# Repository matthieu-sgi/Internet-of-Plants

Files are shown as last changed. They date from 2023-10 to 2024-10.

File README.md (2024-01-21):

# Internet of Plants

The **Internet of Plants** is an innovative project that revolutionizes the way we interact with and monitor plants. By transforming plants into living sensors, we create a bridge between nature and technology. In this project, we utilize the interaction (touch) you have with the plant and its humidity level to generate real-time sonification of the data. This not only enriches our connection with nature but also provides valuable insights into plant health and well-being.

## Table of Contents

- [Introduction](#introduction)
- [Project Overview](#project-overview)
- [Hardware](#hardware)
- [Software](#software)
- [Internet and networking](#internet-and-networking)
- [Roadmap](#roadmap)

## Introduction

The Internet of Plants is a creative exploration into the realm of biotechnology and sensory augmentation. It enables us to perceive and interpret data from the natural world in a novel and engaging way. With this project, we hope to inspire a deeper appreciation for the environment and promote sustainable practices through data-driven insights. This by conducting a musical art experience.

## Project Overview

### How it Works

The core concept of the Internet of Plants is to use plants as living sensors. We collect data from the plants through two main channels:

1. **Interaction (Touch):** When you interact with a plant by touching its leaves or stems, the project senses this interaction and translates it into a unique sound.

2. **Humidity Level:** We monitor the humidity level of the soil. Changes in humidity are reflected through a different set of sounds, providing valuable feedback on the plant's environmental conditions.

### Repository Structure

    Internet of Plants/
    |-- README.md
    |-- software/
    |   |-- [Software files and source code]
    |-- hardware/
    |   |-- [Hardware design files]
    |-- media/
    |   |-- [Image files related to the project]
    |-- documentation/
    |   |-- poster/
    |   |   |-- [Poster files]
    |   |-- BOM/ # Bill of Materials
    |   |   └── pcb_bom_iop_budget.csv # BOM for the PCB and the budget
    |   |-- user_study/
    |   └──   |-- [User study files]
    └── acknowledgements.md

## Hardware

The hardware for the Internet of Plants is based on a custom-designed Printed Circuit Board (PCB). You can find detailed information about the PCB design, components, and assembly in the **PCB** folder of this repository.

## Software

The software component of this project is responsible for collecting data from the plant sensors and converting it into sonified feedback. It involves signal processing, data visualization, and sound synthesis. Detailed instructions on setting up and running the software can be found in the **Software** section of this repository.

## Internet and networking

The PCBs are made out of an ESP32, a MCU that has Wifi capabilities. The ESP32 is connected to a server that runs a Pure Data. The Pure Data patch is responsible for the sonification of the data.
This allows to connect several and many plants to the same server and to have a centralized sonification of the data.
This is done in order to do a musical art experience and to go to Ars Electronica with the project.

## Deployment

Refer to [deployment.md](https://github.com/matthieu-sgi/Internet-of-Plants/blob/main/deployment.md).

## Roadmap

- [x] Test the electronic filter for the touch interaction
- [x] Test the sound amplification circuit
- [x] Build a prototyping PCB
- [x] Build a software embedded synthesizer
- [x] Do sonification with the prototyping PCB
- [x] Build the "Internet"
- [ ] Build the final PCB
- [x] Build the PureData patch on server
- [ ] Check the correlation between humidity and sensor values
- [x] play some sound from the micro sd
- [ ] check on the maths (the EMA is working well, the ema_std not so much)
- [ ] develop web gui for the esp32 (to change the wifi network)

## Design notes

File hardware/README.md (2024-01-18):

# Hardware Directory

## Directory Structure

    hardware/
    |-- README.md
    |-- PCB/
    |   |-- [Full KiCad Project Files]
    |-- PCB Devkit/
    |   |-- [Full KiCad Project Files]

Overview

 - [PCB](https://github.com/matthieu-sgi/Internet-of-Plants/tree/main/hardware/pcb): Final version of hardware. Currently in development.
 - [PCB Devkit](https://github.com/matthieu-sgi/Internet-of-Plants/tree/main/hardware/pcb_devkit): ESP32 WROOM 32 Devkit for rapid prototyping. First version of hardware. Not in development anymore.

## TO DO:

- [ ] Fix the pcb devkit
- [ ] Finish the main pcb

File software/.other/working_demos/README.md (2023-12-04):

# Working demo folder

## analog_serial_data demo

This demo is reading the analog data using the esp32. Then the data is sent through the serial port to the computer. The data is read by the python script and plotted in real time. The python script is sending the data using socket to a pure-data server. The pure-data server is doing the sonification in real-time.

### How to run the demo

1. Upload the analog_serial_data/src/main.cpp to the esp32
2. Configure the python script to use the correct serial port. Also specify the ip address and port of the pure-data server.
3. Run the python script :
```bash
python3 analog_serial_data/src/app.py
```
4. Run the pure-data server patch
```bash
pure-data analog_serial_data/src/receiveTCP.pd
```

### Acknowledgement

Thanks to [Nicolas Stas (@COLVERTYETY)](https://github.com/COLVERTYETY) for the help on the demo.

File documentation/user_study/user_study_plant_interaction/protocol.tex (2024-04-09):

\section{Methodology}

\subsection{Participants}

The study is conducted on 22 participants. Participants are mainly composed of engineering students. The participant set includes 15 males and 7 females.
The age of participants is between 19 and 22 years old. Exception for three participants that are older than 22 years old. 

\subsection{Procedure}

We introduced the subject telling participants : 
"We're in the very near future. You are looking at plants that make music when you physically interact with them (it is not actually the case, but imagine it). Explore their capabilities."
Using this prompt, we tried not to bridle them to much but approach them to the physical interaction component.
Subsequently, participants were given time to explore the potential musical capacities of the plants at their own pace.
We conducted the study without providing any guidance during the exploration phase.
In instances where participants encountered difficulty initiating exploration, the prompt was reiterated to encourage the participants to explore.
This methodological approach was designed to capture the intuitive and natural human-plant interaction.
Also, we avoided any kind of communication or talking between 2 participants to reduce the potential bias.

\subsection{Materials/Tools}

To proceed and conduct this user study, we chose 3 different plants from 3 different species.

\newpage

\subsubsection{Dracaena}
It has long leaves and fragile perceived trunk but also flexible. The plant is 95 cm tall.

\begin{figure}[ht]
    \centering
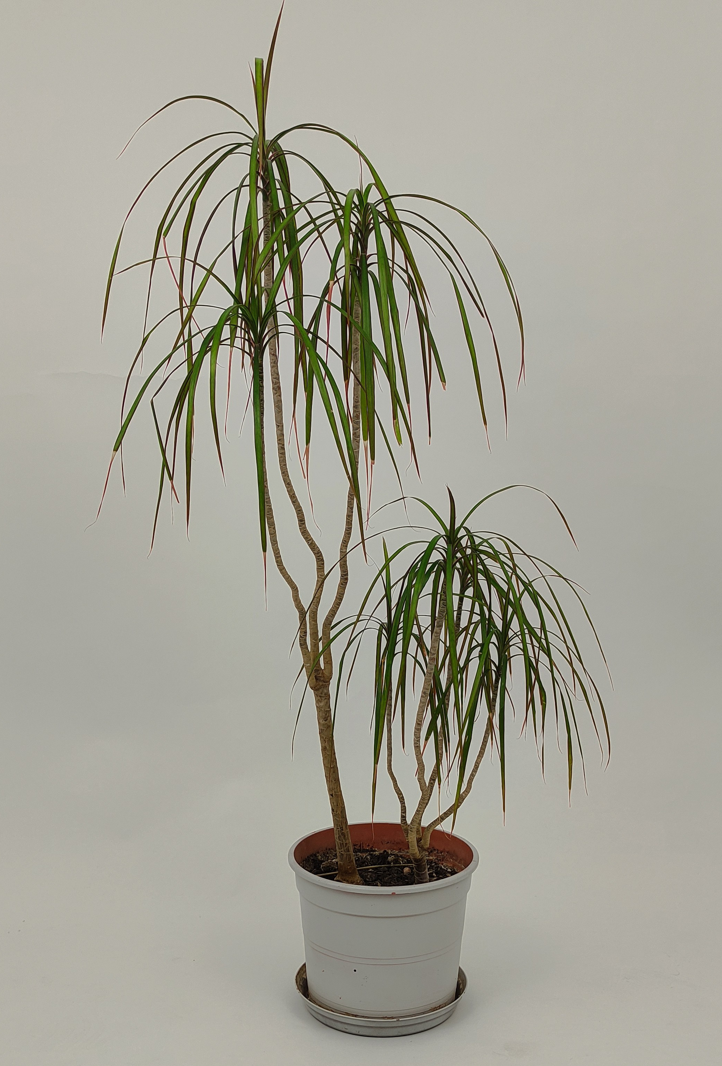
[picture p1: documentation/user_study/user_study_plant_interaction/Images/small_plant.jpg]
    
    \caption{The plant N°1 is a \textit{Dracaena}.}
    
    \vspace{-0.5cm}
    \label{fig:small_plant}
    \vspace{0.2cm}
\end{figure}

\subsubsection{Pachira glabra}

We chose to use this plant for its large leaves and its wide trunk.
The plant is 110 cm tall.
\begin{figure}[ht]
    \centering
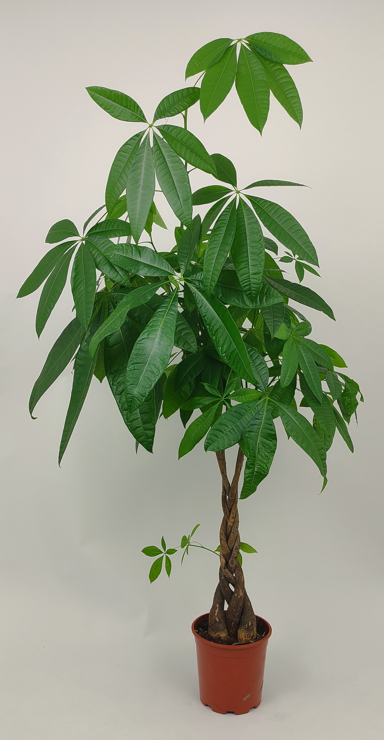
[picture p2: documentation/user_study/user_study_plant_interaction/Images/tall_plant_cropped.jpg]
    
    \caption{The plant N°2 is a \textit{Pachira glabra}.}
    
    \vspace{-0.5cm}
    \label{fig:tall_plant}
    \vspace{0.2cm}
\end{figure}

\newpage

\subsubsection{Dypsis lutescens}

The \textit{Dypsis lutescens} is composed of many trunks and stems. On top of that, the leaves are numerous and tight. The plant is 100cm tall.

\begin{figure}[ht]
    \centering
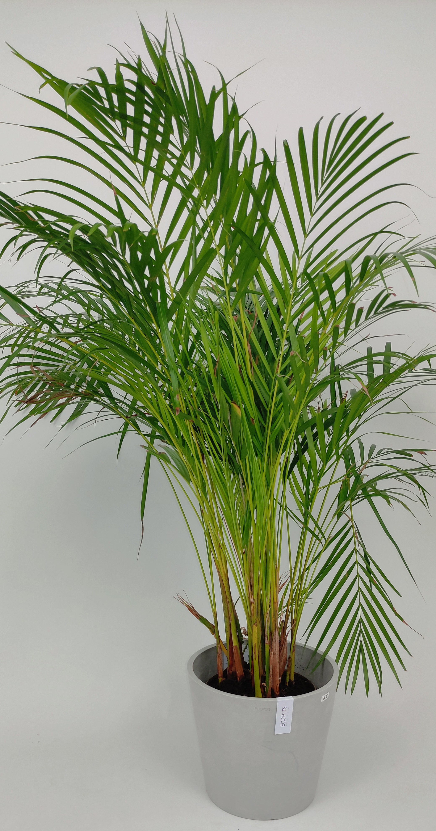
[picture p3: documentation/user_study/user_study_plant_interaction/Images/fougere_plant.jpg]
    
    \caption{The plant N°3 is a \textit{Dypsis lutescens}.}
    
    \vspace{-0.5cm}
    \label{fig:fougere_plant}
    \vspace{0.2cm}
\end{figure}

\subsubsection{The experimental space}

The experimental space featured three distinct levels of height, each corresponding to one of the three plants introduced to participants.

\begin{figure}[h]
    \centering
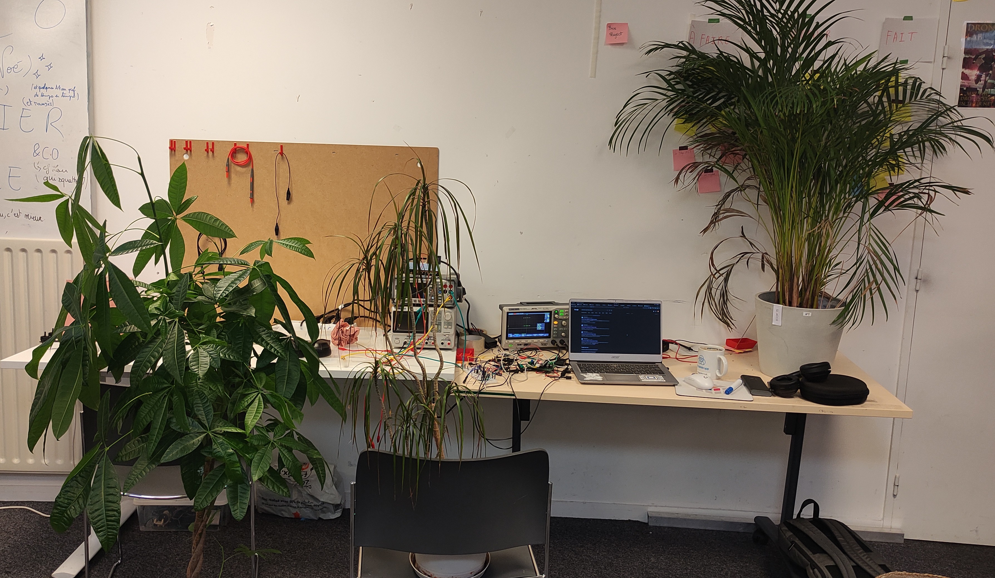
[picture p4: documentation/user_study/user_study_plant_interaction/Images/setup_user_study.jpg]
    
    \caption{User study space setup. The set-up is built from our lab space.}
    
    \vspace{-0.5cm}
    \label{fig:setup_user_study}
    \vspace{0.2cm}
\end{figure}

\newpage

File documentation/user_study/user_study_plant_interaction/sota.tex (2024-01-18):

\section{State of the art}

In the HCI world, the question of the human-plant interaction has already been asked. 
Seow and al. developed a framework that augment a \textit{Mimosa Pudica} \cite{seowPudicaFrameworkDesigning2022}. They designed and conducted a user study to test their framework
Their user study is following a script of question that are based on the experience with the already built framework.

A more technical approach is explained by Poupyrev and al. with the \textit{Botanicus Interacticus} framework \cite{poupyrev2012botanicus}.
The report does not present a user study but only the prototype for an art exhibition \cite{kasik2012hands}.
The information on the way to interpret the plant interaction is vague and only talk about machine learning.

R.F.M. worked on the interaction grade schoolers can develop with their plants \cite{ledo2019music}. 
The study tries to capture the human-plant link through sensors and also supervise the growing of the plants.
Contrary to Seow and al. \cite{seowPudicaFrameworkDesigning2022}, he is only using non-intrusive ways to capture the interaction.

The human-plant interaction and collaboration is studied in different field of research. 
For example in the psychologic domain, Elings studied the benefits of horticultural therapy which includes the interaction between patient and pants during therapy \cite{elings2006people}.

This study will be conducted using the human centered paradigm in the human-plant interface.
The reflection about the position of the plant or the human in the human-plant interaction is also a subject to be discuss.
Indeed, Loh and al. studied and criticize the human centered HCI that is reducing the plant to an actuator \cite{lohMorethanhumanTurnHumanplant2024}.

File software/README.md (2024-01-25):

# Software and Firmware

## Project Structure

The project is structured as follows:

```
.
├── README.md
├── firmware # Contains the firmware for the ESP32
│   ├── src/ # Contains the source code
│   ├── lib/ # Contains the libraries
│   ├── platformio.ini # Contains the platformio configuration
│   └── test/ # Contains the tests
├── server # Contains the software for the server
│   ├── modules/ # Contains the python modules
│   │   ├── IOPModule # compute the data
│   │   ├── IOPReceiver # receive the data
│   │   ├── IOPSender # send the data
│   │   └── IOPServer # make the brigde betwen compute, receiver and sender
│   ├── patches/ # Contains the Pure Data patches
│   ├── requirements.txt # Contains the python dependencies
│   ├── main.py # Contains the main python script
│   ├── install.sh # Install the python dependencies, the systemd service and the patches
│   ├── start.sh # Start the server
│   └── test/ # Contains the tests│
└── .other # other stuff
    ├── tests/ # Old tests
    └── working_demos/ # Old working demos

```

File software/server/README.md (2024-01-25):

# Server 

## Installation

```bash
sudo ./install.sh
```

## Software architecture

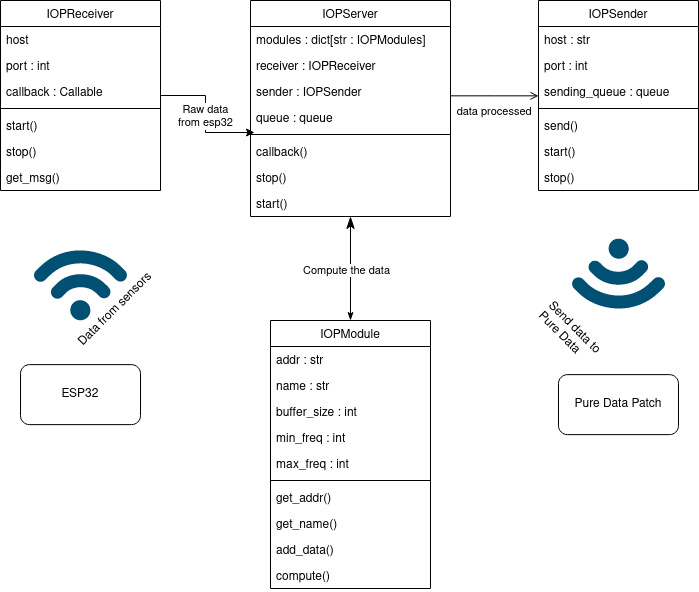
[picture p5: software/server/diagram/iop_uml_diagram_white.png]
Software architecutre


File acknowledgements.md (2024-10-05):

# Acknowledgments

I would like to express my gratitude to the following individuals and communities for their valuable contributions and support throughout the development of this project:

## Contributors

- Jakub Nikonowicz and Łukasz Matuszewski from Politechnika Poznańska University - For their electronical filter design.
- [Nicolas Stas](https://github.com/COLVERTYETY) - For his contributions on this project and on all the other projects we worked on.
- Jérôme Béarel - For his accurate advice.

## Mentors

- [Clément Duhart](https://github.com/slash6475) - Provide guidance and support throughout the development process.

## Others

- [IFT](https://ift.devinci.fr/) - For providing the resources and support needed to complete this project.

Your support has been crucial to the success of this project. Thank you for being a part of this journey!

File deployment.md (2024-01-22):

# Deployment

## Flashing the ESP32

### Requirements

- [PlatformIO](https://platformio.org/)
- [Python 3](https://www.python.org/downloads/)

### Instructions

Go to the folder `software/firmware/`.
Modify the 'src/main.cpp' file to set the correct Wifi credentials and server ip.

Then run the following command:

```bash
pio run -t upload
```

##  Run the server

### Requirements

- [Python 3](https://www.python.org/downloads/)
- [Pure Data](https://puredata.info/downloads/pure-data)

### Instructions

Go to the folder `software/server/` and run the following command:

```bash
sh install.sh
or
./install.sh
```

This script will install the required Python packages and create and enable the server.service.

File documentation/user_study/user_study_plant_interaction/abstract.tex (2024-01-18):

\section*{Abstract}
\begin{textbf}

This study explores human-plant interaction.
This study has been conducted in order to understand what kind of interaction we have to detect in order to have the best and more natural kind of interaction with plants.
The results will be applied in the Internet of Plants (IoP) project which intends to create a fully connected bio-organ system.
The IoP is looking to reduce the gap between humans and plants by creating a symbiotic relationship between 
nature and technology. We envision a world where our daily objects are responsive.

\end{textbf}

\begin{figure}[ht]
    \centering
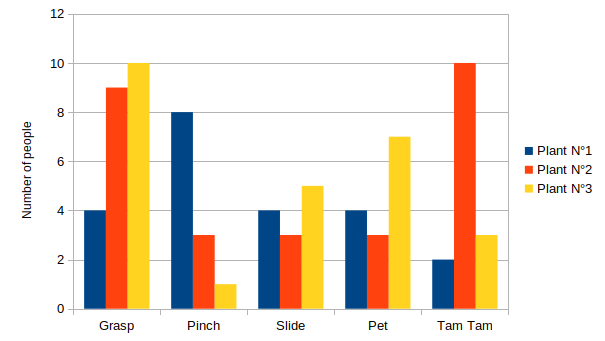
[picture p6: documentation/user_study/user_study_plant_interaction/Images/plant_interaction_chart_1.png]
    
    \caption{Bar chart that is extracting the main types of interaction regarding each plants.}
    
    \vspace{-0.5cm}
    % \label{fig:setup_user_study}
    \vspace{0.2cm}
\end{figure}

\newpage

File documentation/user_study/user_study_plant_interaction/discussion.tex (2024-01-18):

\section{Discussion}

Looking at the results, the interaction were various depending on the plant. 
Thus, we can extract main interactions that are linked to the plant type. 
Looking at table \ref{tab:results}, people are more inclined to use their hands as tam tam or grasp the \textit{Pachira glabra}. 
However, for the \textit{Dracaena} users prefer to pinch the trunk or leave. 
Participants decided to grasp whether a pack of trunk or leaves when it came to \textit{Dypsis lutescens}.
This is induced by many factors including the leaves shape, the width of the trunk.

It was observed that when the plants were positioned at higher elevations on the table, individuals tended to engage more with the trunk of the plants.

Looking at table \ref{tab:results}, we decided to group interaction. This was done by grouping type of interaction depending on 3 main factors :

\begin{itemize}
    \item The intensity factor : what is the intensity of the interaction (ex : pinch is lighter than grasp)
    \item The spatial factor : what is the interaction displacement.
    \item The duration factor : what is the interaction duration (ex : tam tam is instantaneous).
\end{itemize}

The "Group 1" includes the pinch and grasp interaction. Indeed, looking at the 3 factors we defined, 
the pinch and grasp are high in intensity and long in duration but people stay still in space.
This group of interaction can be defined as \textbf{binary interaction}. The user is either grasping or not.

The "Group 2" includes the slide. The slide interaction is long in time, it moves in space but low in intensity.
This group of interaction can be defined as \textbf{continuous interaction}.

Whereas, the "Group 3" includes the pet and Tam Tam. 
These 2 interactions are really high in intensity, people usually tam tam and pet in different places but those interactions are short in time. 
This group is defined as \textbf{repetitive interaction}. The user is repeating the same action over and over again.

\begin{figure}

    \begin{minipage}{.5\linewidth}
    \centering
    \subfloat[]{
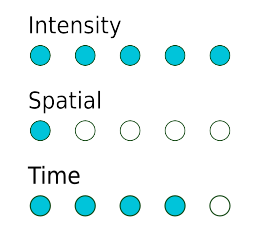
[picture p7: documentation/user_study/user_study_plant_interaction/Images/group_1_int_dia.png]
        
        
        \label{fig:interactions:subfig:group1}
        }
    \end{minipage}%
    \begin{minipage}{.5\linewidth}
    \centering
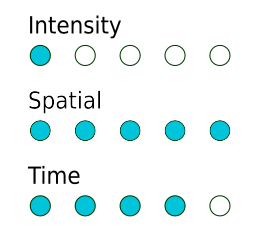
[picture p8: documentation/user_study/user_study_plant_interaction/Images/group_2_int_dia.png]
    \subfloat[]{\label{fig:interactions:subfig:group2}}
    \end{minipage}\par\medskip
    \centering
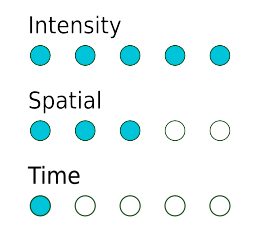
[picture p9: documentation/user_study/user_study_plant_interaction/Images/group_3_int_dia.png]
    \subfloat[]{\label{fig:interactions:subfig:group3}}
    
    \caption{Figure showing graphically the intensity of the 3 types of factors we defined. (a) Group 1 : pinch and grasp. (b) Group 2 : slide. (c) Group 3 : pet and tam tam.}
    \label{fig:main}
    \end{figure}

The participants we interviewed introduced a bias in the results.
They were all students from the engineering school and thus, they all had a similar background.
Some of them were already familiar with the project.

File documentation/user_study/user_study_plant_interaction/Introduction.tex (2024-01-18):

\section{Introduction}

Plants represent a full ecosystem of evolution, adaptation and communication.

In the context of the Internet of Plant (IoP) project, this study aims to extract the natural interaction between people and plants.
This experiment explores the interactions the IoP device will have to detect to create a symbiotic relation between human and plants. 
The physical touch is the starting point of a sonification process.
Sonification is “the use of non-speech audio to convey information or perceptualize data” \cite{kramer2010sonification}.
Three distinct plant species—\textit{Dypsis lutescens, Pachira glabra, and Dracaena}—are employed as subjects to extract user perceptions and interactions within this framework. 

% Three plant species, Dypsis lutescens, Pachira glabra, and Dracaena, serve as conduits for inquiry, 
% prompting participants to envisage that these botanical entities create and generate sounds upon physical interaction.

The methodology engages students from the engineering school and two researchers.
The participants are asked to interact with the plants and imagine the sounds that could be generated by the plants.

The correlation between plant height and trunk interactions reveals environmental factors impacting human-plant dynamics.
Additionally, interactions are categorized based on intensity, spatial displacement, and duration.

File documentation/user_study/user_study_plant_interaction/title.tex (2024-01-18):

\makeatletter
\begin{titlepage}
\centering
\vfill
\vspace*{\fill}
{\bfseries\huge
        \@title
        \vskip2cm
        
    }
    {\large
    \@author
    % \@contributors
    }
\vfill
\begin{figure}[h]
    \centering
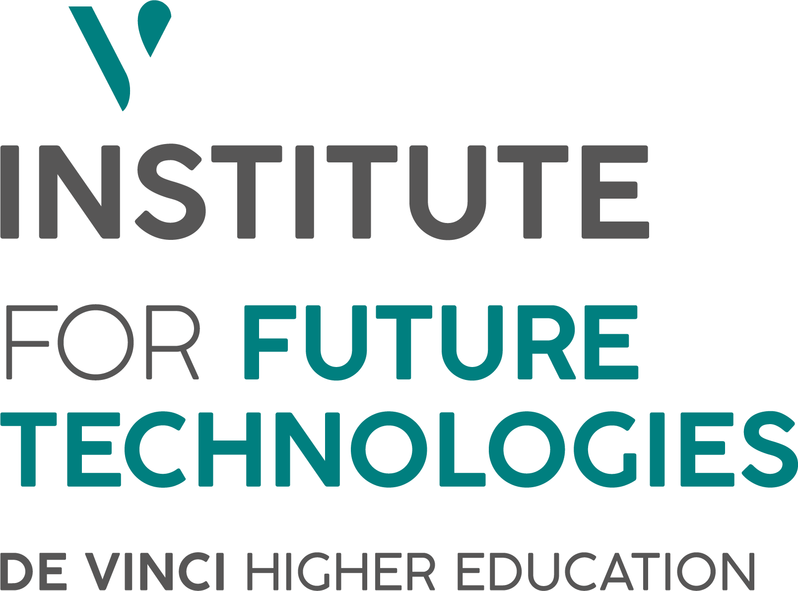
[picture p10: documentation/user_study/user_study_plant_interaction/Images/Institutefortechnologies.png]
    
    %\caption{Répartition des divers datasets}
    \label{fig:logo}
\end{figure}
\vfill
\vfill
\addtocounter{page}{1}
\end{titlepage}

\makeatother

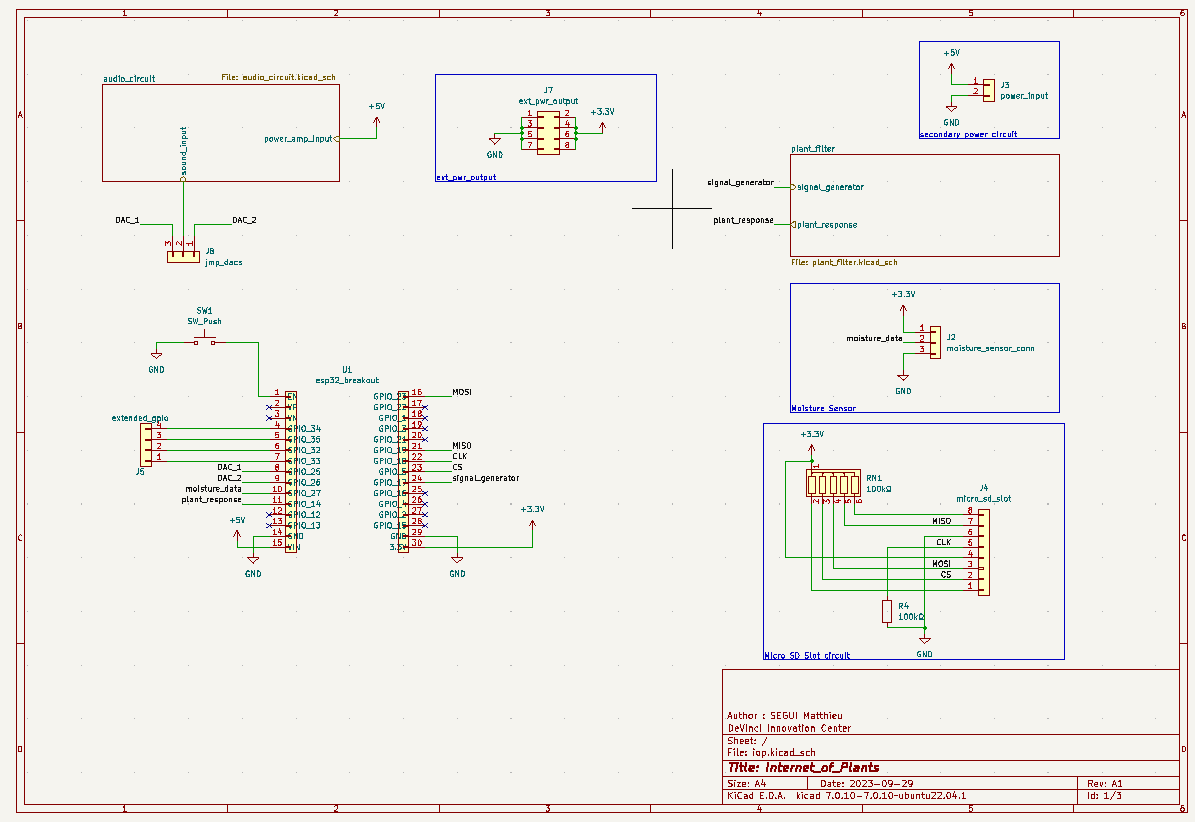
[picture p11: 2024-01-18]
media/iop_schematic_v1.png

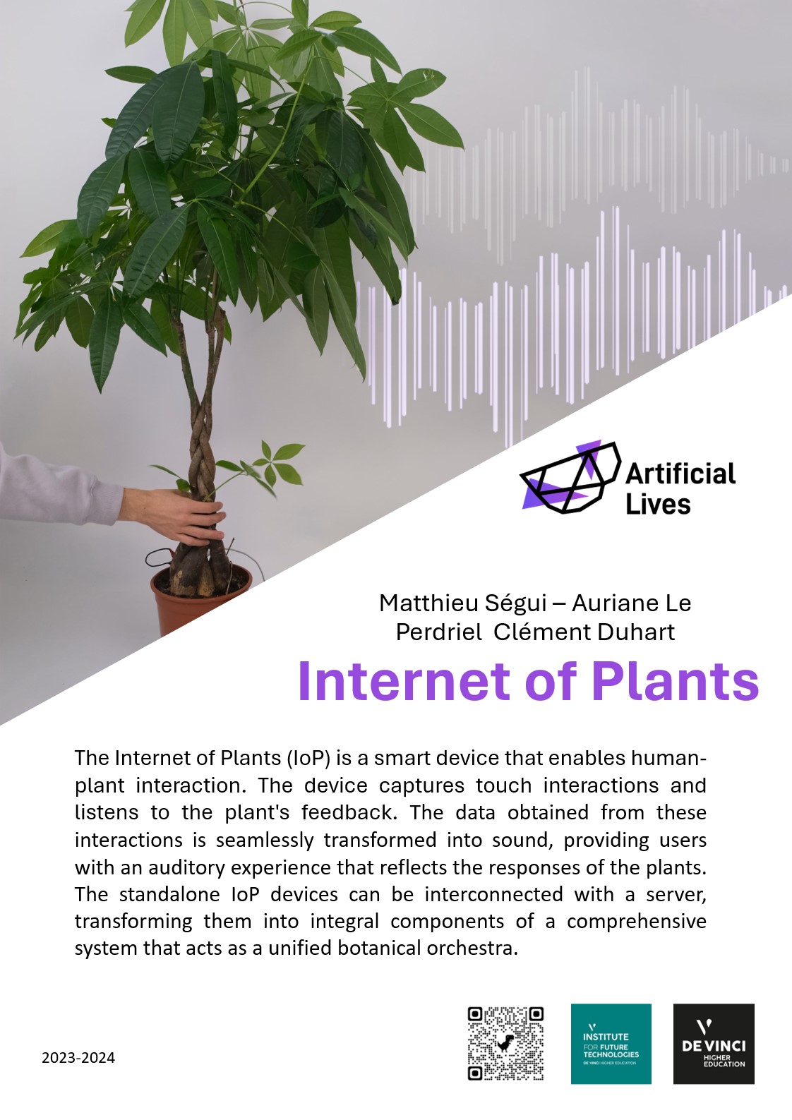
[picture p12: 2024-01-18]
documentation/poster/poster.jpg

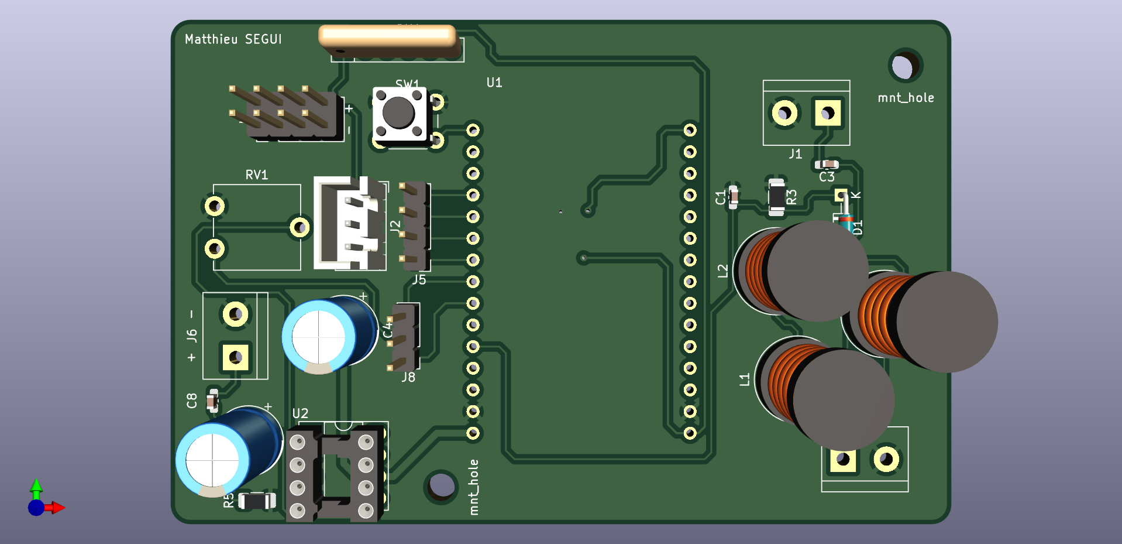
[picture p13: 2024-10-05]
hardware/pcb_devkit/front_iop_3D_view.png

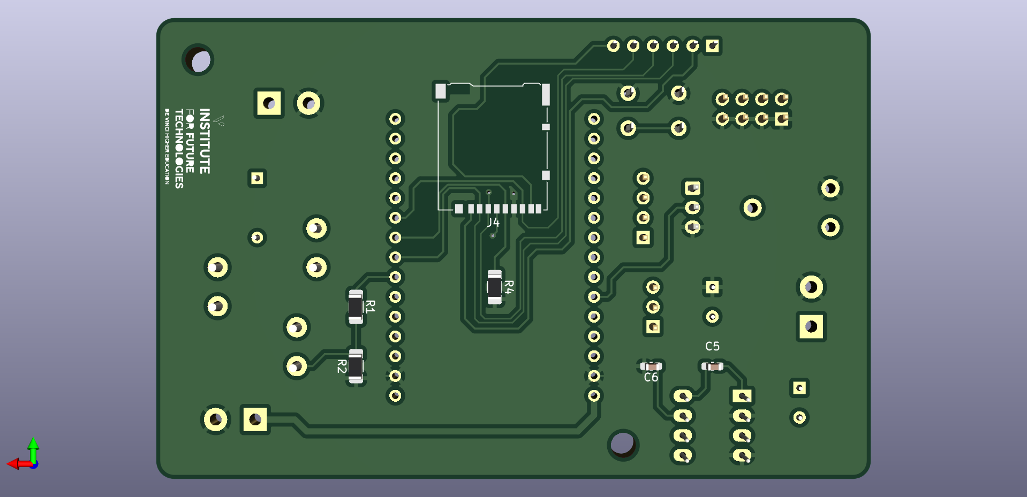
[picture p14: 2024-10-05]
hardware/pcb_devkit/back_iop_3D_view.png

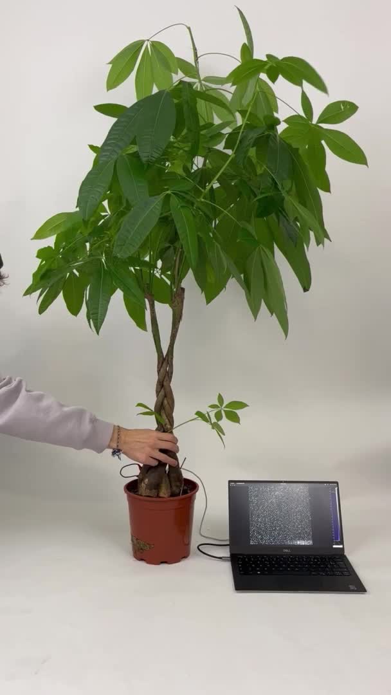
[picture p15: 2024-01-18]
media/frame_out.jpg

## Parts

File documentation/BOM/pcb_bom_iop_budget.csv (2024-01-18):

Id | Designator | Footprint | Quantity | Designation | Supplier and ref | Price | Total price
1 | RN1 | R_Array_SIP6 | 1 | 100kΩ | https://fr.rs-online.com/web/p/reseaux-de-resistances/5223494 | 0.19 € | 0.19 €
2 | J8 | PinHeader_1x03_P2.54mm_Vertical | 1 | jmp_dacs |  |  | 0.00 €
3 | R5 | R_1206_3216Metric_Pad1.30x1.75mm_HandSolder | 1 | 10Ω |  |  | 0.00 €
4 | D1 | D_DO-34_SOD68_P7.62mm_Horizontal | 1 | D |  |  | 0.00 €
5 | U1 | esp32_breakout | 1 | esp32_breakout |  | 10.00 € | 10.00 €
6 | U2 | DIP-8_W7.62mm_Socket_LongPads | 1 | LM386 | https://fr.rs-online.com/web/p/circuits-integres-amplificateurs-audio/1244528 | 1.30 € | 1.30 €
7 | SW1 | SW_PUSH_6mm | 1 | SW_Push | https://fr.rs-online.com/web/p/interrupteurs-tactiles/4791429 | 0.10 € | 0.10 €
8 | C4 | CP_Radial_D8.0mm_P3.80mm | 1 | 100μF |  |  | 0.00 €
9 | L3,L2,L1 | L_Radial_D10.0mm_P5.00mm_Fastron_07P | 3 | 3.3mH | https://www.mouser.fr/ProductDetail/Bourns/RL875S-332K-RC | 1.52 € | 4.56 €
10 | J2 | JST_XH_B3B-XH-A_1x03_P2.50mm_Vertical | 1 | moisture_sensor_conn |  |  | 0.00 €
11 | J5 | PinHeader_1x04_P2.54mm_Vertical | 1 | extended_gpio |  |  | 0.00 €
12 | J1 | TerminalBlock_bornier-2_P5.08mm | 1 | plant_connector | https://fr.rs-online.com/web/p/borniers-pour-circuits-imprimes/7901064 | 0.69 € | 0.69 €
13 | J7 | PinHeader_2x04_P2.54mm_Vertical | 1 | ext_pwr_output |  |  | 0.00 €
14 | C8,C5 | C_0603_1608Metric_Pad1.08x0.95mm_HandSolder | 2 | 10μF |  |  | 0.00 €
15 | J3 | TerminalBlock_bornier-2_P5.08mm | 1 | power_input | https://fr.rs-online.com/web/p/borniers-pour-circuits-imprimes/7901064 | 0.69 € | 0.69 €
16 | C3,C6 | C_0603_1608Metric_Pad1.08x0.95mm_HandSolder | 2 | 10nF |  |  | 0.00 €
17 | C7 | CP_Radial_D8.0mm_P3.80mm | 1 | 47μF |  |  | 0.00 €
18 | C2 | C_0603_1608Metric_Pad1.08x0.95mm_HandSolder | 1 | 1nF |  |  | 0.00 €
19 | J6 | TerminalBlock_bornier-2_P5.08mm | 1 | speaker_output | https://fr.rs-online.com/web/p/borniers-pour-circuits-imprimes/7901064 | 0.69 € | 0.69 €
20 | RV1 | Potentiometer_ACP_CA9-V10_Vertical | 1 | R_Potentiometer |  |  | 0.00 €
21 | R3 | R_1206_3216Metric_Pad1.30x1.75mm_HandSolder | 1 | 1MΩ |  |  | 0.00 €
22 | C1 | C_0603_1608Metric_Pad1.08x0.95mm_HandSolder | 1 | 100pF |  |  | 0.00 €
23 | R4 | R_1206_3216Metric_Pad1.30x1.75mm_HandSolder | 1 | 100kΩ |  |  | 0.00 €
24 | R1 | R_1206_3216Metric_Pad1.30x1.75mm_HandSolder | 1 | 10kΩ |  |  | 0.00 €
25 | R2 | R_1206_3216Metric_Pad1.30x1.75mm_HandSolder | 1 | 4.7kΩ |  |  | 0.00 €
26 | J4 | microSD_HC_Hirose_DM3AT-SF-PEJM5 | 1 | micro_sd_slot | https://www.mouser.fr/ProductDetail/Hirose-Connector/DM3AT-SF-PEJM5?qs=LZSZKJVF%252B2WTDKp%252BR7IYAQ%3D%3D | 2.45 € | 2.45 €
 |  | Moisture sensor | 1 |  | https://www.mouser.fr/ProductDetail/Seeed-Studio/101020614?qs=u16ybLDytRZLXly%252BMAdDNQ%3D%3D | 6.05 € | 6.05 €
 |  | PCB fabrication | 1 |  |  | 40.00 € | 40.00 €
 |  | TOTAL |  |  |  |  | 66.73 €

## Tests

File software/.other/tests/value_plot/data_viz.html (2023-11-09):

# Not live value part of the code¶

In [ ]:

import matplotlib.pyplot as plt
import pandas as pd
import random

In [ ]:

# Read in the data
df_touched = pd.read_csv('data_touched.csv')
df_untouched = pd.read_csv('data_untouched.csv')

In [ ]:

# pandas display the touched data summary
df_touched.describe()

Out[ ]:

| 100 kHz | 101 kHz | 102 kHz | 103 kHz | 104 kHz | 105 kHz | 106 kHz | 107 kHz | 108 kHz | 109 kHz | ... | 290 kHz | 291 kHz | 292 kHz | 293 kHz | 294 kHz | 295 kHz | 296 kHz | 297 kHz | 298 kHz | 299 kHz
count | 300.00000 | 300.000000 | 300.000000 | 300.000000 | 300.000000 | 300.000000 | 300.000000 | 300.000000 | 300.000000 | 300.000000 | ... | 300.000000 | 300.000000 | 300.000000 | 300.000000 | 300.000000 | 300.000000 | 300.000000 | 300.000000 | 300.000000 | 300.000000
mean | 0.08940 | 0.100500 | 0.071300 | 0.099167 | 0.093167 | 0.085600 | 0.091400 | 0.051600 | 0.060300 | 0.085700 | ... | 0.072300 | 0.083300 | 0.099500 | 0.082533 | 0.089200 | 0.097000 | 0.071833 | 0.088067 | 0.093567 | 0.083767
std | 0.07094 | 0.062944 | 0.066995 | 0.063827 | 0.061266 | 0.069911 | 0.063272 | 0.060699 | 0.066405 | 0.056425 | ... | 0.060287 | 0.066061 | 0.066484 | 0.063432 | 0.057548 | 0.065925 | 0.064156 | 0.064933 | 0.069129 | 0.065634
min | 0.00000 | 0.000000 | 0.000000 | 0.000000 | 0.000000 | 0.000000 | 0.000000 | 0.000000 | 0.000000 | 0.000000 | ... | 0.000000 | 0.000000 | 0.000000 | 0.000000 | 0.000000 | 0.000000 | 0.000000 | 0.000000 | 0.000000 | 0.000000
25% | 0.05000 | 0.050000 | 0.000000 | 0.060000 | 0.050000 | 0.040000 | 0.050000 | 0.000000 | 0.000000 | 0.050000 | ... | 0.040000 | 0.050000 | 0.050000 | 0.040000 | 0.050000 | 0.050000 | 0.000000 | 0.050000 | 0.050000 | 0.040000
50% | 0.07000 | 0.090000 | 0.050000 | 0.080000 | 0.080000 | 0.070000 | 0.080000 | 0.040000 | 0.040000 | 0.070000 | ... | 0.060000 | 0.060000 | 0.080000 | 0.070000 | 0.070000 | 0.080000 | 0.060000 | 0.070000 | 0.080000 | 0.070000
75% | 0.13000 | 0.122500 | 0.110000 | 0.130000 | 0.120000 | 0.122500 | 0.130000 | 0.090000 | 0.100000 | 0.110000 | ... | 0.110000 | 0.110000 | 0.140000 | 0.120000 | 0.120000 | 0.130000 | 0.102500 | 0.122500 | 0.140000 | 0.130000
max | 0.35000 | 0.340000 | 0.360000 | 0.390000 | 0.320000 | 0.300000 | 0.380000 | 0.260000 | 0.280000 | 0.260000 | ... | 0.270000 | 0.310000 | 0.370000 | 0.270000 | 0.300000 | 0.490000 | 0.270000 | 0.340000 | 0.320000 | 0.300000

8 rows × 200 columns

In [ ]:

# pandas display the untouched data summary
df_untouched.describe()

Out[ ]:

| 100 kHz | 101 kHz | 102 kHz | 103 kHz | 104 kHz | 105 kHz | 106 kHz | 107 kHz | 108 kHz | 109 kHz | ... | 290 kHz | 291 kHz | 292 kHz | 293 kHz | 294 kHz | 295 kHz | 296 kHz | 297 kHz | 298 kHz | 299 kHz
count | 300.000000 | 300.000000 | 300.000000 | 300.000000 | 300.000000 | 300.000000 | 300.000000 | 300.000000 | 300.000000 | 300.000000 | ... | 300.000000 | 300.000000 | 300.000000 | 300.000000 | 300.000000 | 300.000000 | 300.000000 | 300.000000 | 300.000000 | 300.000000
mean | 0.869433 | 0.596767 | 0.432100 | 0.619833 | 0.508900 | 0.610033 | 0.570400 | 0.421233 | 0.425200 | 0.473200 | ... | 0.793200 | 0.766933 | 1.011667 | 0.877000 | 0.888433 | 1.017100 | 0.767900 | 0.809133 | 0.957567 | 0.786767
std | 0.135765 | 0.098852 | 0.070729 | 0.098689 | 0.094779 | 0.077535 | 0.070823 | 0.077036 | 0.077367 | 0.074415 | ... | 0.120702 | 0.099099 | 0.110740 | 0.119828 | 0.126080 | 0.115796 | 0.125154 | 0.110762 | 0.113993 | 0.128234
min | 0.590000 | 0.320000 | 0.270000 | 0.300000 | 0.250000 | 0.400000 | 0.360000 | 0.290000 | 0.300000 | 0.350000 | ... | 0.590000 | 0.530000 | 0.660000 | 0.620000 | 0.630000 | 0.620000 | 0.590000 | 0.590000 | 0.660000 | 0.600000
25% | 0.767500 | 0.570000 | 0.380000 | 0.590000 | 0.440000 | 0.580000 | 0.520000 | 0.370000 | 0.370000 | 0.420000 | ... | 0.720000 | 0.697500 | 0.940000 | 0.780000 | 0.800000 | 0.990000 | 0.690000 | 0.720000 | 0.880000 | 0.680000
50% | 0.860000 | 0.610000 | 0.420000 | 0.630000 | 0.480000 | 0.610000 | 0.570000 | 0.400000 | 0.400000 | 0.450000 | ... | 0.760000 | 0.750000 | 1.030000 | 0.880000 | 0.865000 | 1.040000 | 0.720000 | 0.790000 | 0.980000 | 0.760000
75% | 0.980000 | 0.650000 | 0.470000 | 0.662500 | 0.580000 | 0.650000 | 0.610000 | 0.460000 | 0.470000 | 0.510000 | ... | 0.840000 | 0.820000 | 1.090000 | 0.950000 | 0.990000 | 1.080000 | 0.800000 | 0.900000 | 1.040000 | 0.850000
max | 1.230000 | 1.010000 | 0.690000 | 0.850000 | 0.770000 | 0.850000 | 0.840000 | 0.700000 | 0.780000 | 0.720000 | ... | 1.430000 | 1.160000 | 1.280000 | 1.170000 | 1.230000 | 1.330000 | 1.190000 | 1.140000 | 1.260000 | 1.230000

8 rows × 200 columns

## Vizualization of the data using line plot¶

The following vizualization is done on the untouched dataset

In [ ]:

df_untouched[['100 kHz', '150 kHz', '200 kHz','250 kHz', '299 kHz']].plot(legend=True, kind = 'line', figsize=(25, 5), xlabel='Value id', ylabel='Voltage')
# print another plot with different columns 
df_untouched[['100 kHz', '101 kHz','102 kHz', '103 kHz', '103 kHz']].plot(legend=True, kind = 'line', figsize=(25, 5), xlabel='Value id', ylabel='Voltage')
plt.show()

The following vizualization is done on the touched dataset

In [ ]:

df_touched[['100 kHz', '150 kHz', '200 kHz','250 kHz', '299 kHz']].plot(legend=True, kind = 'line', figsize=(25, 5), xlabel='Value id', ylabel='Voltage')
# print another plot with different columns 
df_touched[['100 kHz', '101 kHz','102 kHz', '103 kHz', '103 kHz']].plot(legend=True, kind = 'line', figsize=(25, 5), xlabel='Value id', ylabel='Voltage')
plt.show()

The following visualization is done on the untouched dataset will take 4 randomly chosen value id and display the voltage value

In [ ]:

df_untouched.iloc[1].plot(legend=True, kind = 'line', figsize=(25, 5), xlabel='frequency', ylabel='Voltage response')
df_untouched.iloc[100].plot(legend=True, kind = 'line', figsize=(25, 5), xlabel='frequency', ylabel='Voltage response')
df_untouched.iloc[50].plot(legend=True, kind = 'line', figsize=(25, 5), xlabel='frequency', ylabel='Voltage response')
df_untouched.iloc[299].plot(legend=True, kind = 'line', figsize=(25, 5), xlabel='frequency', ylabel='Voltage response')

Out[ ]:

<AxesSubplot:xlabel='frequency', ylabel='Voltage response'>

The following visualization is done on the touched dataset will take the same 4 randomly chosen value id and display the voltage value

In [ ]:

df_touched.iloc[1].plot(legend=True, kind = 'line', figsize=(25, 5), xlabel='frequency', ylabel='Voltage response')
df_touched.iloc[100].plot(legend=True, kind = 'line', figsize=(25, 5), xlabel='frequency', ylabel='Voltage response')
df_touched.iloc[50].plot(legend=True, kind = 'line', figsize=(25, 5), xlabel='frequency', ylabel='Voltage response')
df_touched.iloc[299].plot(legend=True, kind = 'line', figsize=(25, 5), xlabel='frequency', ylabel='Voltage response')

Out[ ]:

<AxesSubplot:xlabel='frequency', ylabel='Voltage response'>

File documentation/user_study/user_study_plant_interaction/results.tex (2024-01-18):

\section{Results}

The data given by the user study allowed us to define 5 main types of interaction. Those interactions are defined by the way the user interacts with the plant. The 5 main types of interaction are :

\begin{itemize}
    \item Grasp : user uses the whole hand to grab trunk or leaves.
    \item Pinch : user uses 2 to 3 digits to grab trunk or leaves.
    \item Slide : user uses his/her hand or finger to slide on the plant whether is on a leave or on the trunk. The action is continuous.
    \item Pet : user uses his/her hand to cuddle the plant or to pass through the leaves. The user is moving his/her hand in space. She/he is not staying still or staying on a particular object.
    \item Tam Tam : user taps on the plant mainly using the whole hand.
\end{itemize}

Looking at the results, we extracted the table \ref{tab:results}.

\begin{table}[ht]
\begin{tabular}{|l|ll|l|ll|}
\hline
\multirow{2}{*}{Plant/Interaction} & \multicolumn{2}{l|}{Group 1}       & Group 2 & \multicolumn{2}{l|}{Group 3}       \\ \cline{2-6} 
                                   & \multicolumn{1}{l|}{Grasp} & Pinch & Slide   & \multicolumn{1}{l|}{Pet} & Tam Tam \\ \hline
Plant N°1                          & \multicolumn{1}{l|}{4}     & 8     & 4       & \multicolumn{1}{l|}{4}   & 2       \\ \hline
Plant N°2                          & \multicolumn{1}{l|}{9}     & 3     & 3       & \multicolumn{1}{l|}{3}   & 10      \\ \hline
Plant N°3                          & \multicolumn{1}{l|}{10}    & 1     & 5       & \multicolumn{1}{l|}{7}   & 3       \\ \hline
Total                              & \multicolumn{1}{l|}{23}    & 12    & 12      & \multicolumn{1}{l|}{14}  & 15      \\ \hline
\end{tabular}
% \caption*{Plant N°1 : Petite | Plant N°2 : Grande | Plant N°3 : Fougère}
\caption{Raw results extracted from the user study}
\label{tab:results}
\end{table}

\newpage

With the extraction of the result we were able to design a bar chart.
The graph is grouping the interactions by plant. The height of the bar is the number of participants that performed the interaction.
The graph is shown in figure \ref{fig:setup_user_study}.

\begin{figure}[ht]
    \centering
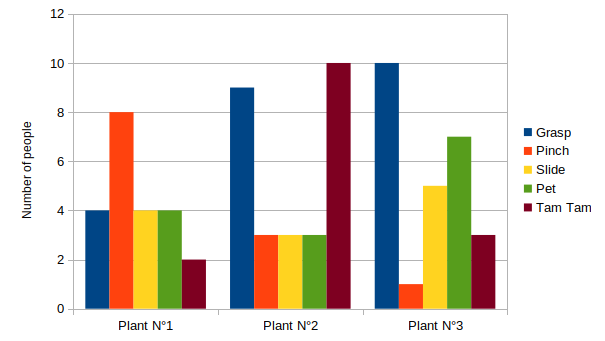
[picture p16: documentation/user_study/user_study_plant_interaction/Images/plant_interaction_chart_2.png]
    
    \caption{Bar chart that is extracting the main types of interaction regarding each plants.}
    
    \vspace{-0.5cm}
    \label{fig:setup_user_study}
    \vspace{0.2cm}
\end{figure}

In the end, of the 22 participants, 15 were already familiar with the project and 7 were not.

% \newpage

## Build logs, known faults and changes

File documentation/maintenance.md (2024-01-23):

# Restart the server

```bash

sudo systemctl restart iop_server

```

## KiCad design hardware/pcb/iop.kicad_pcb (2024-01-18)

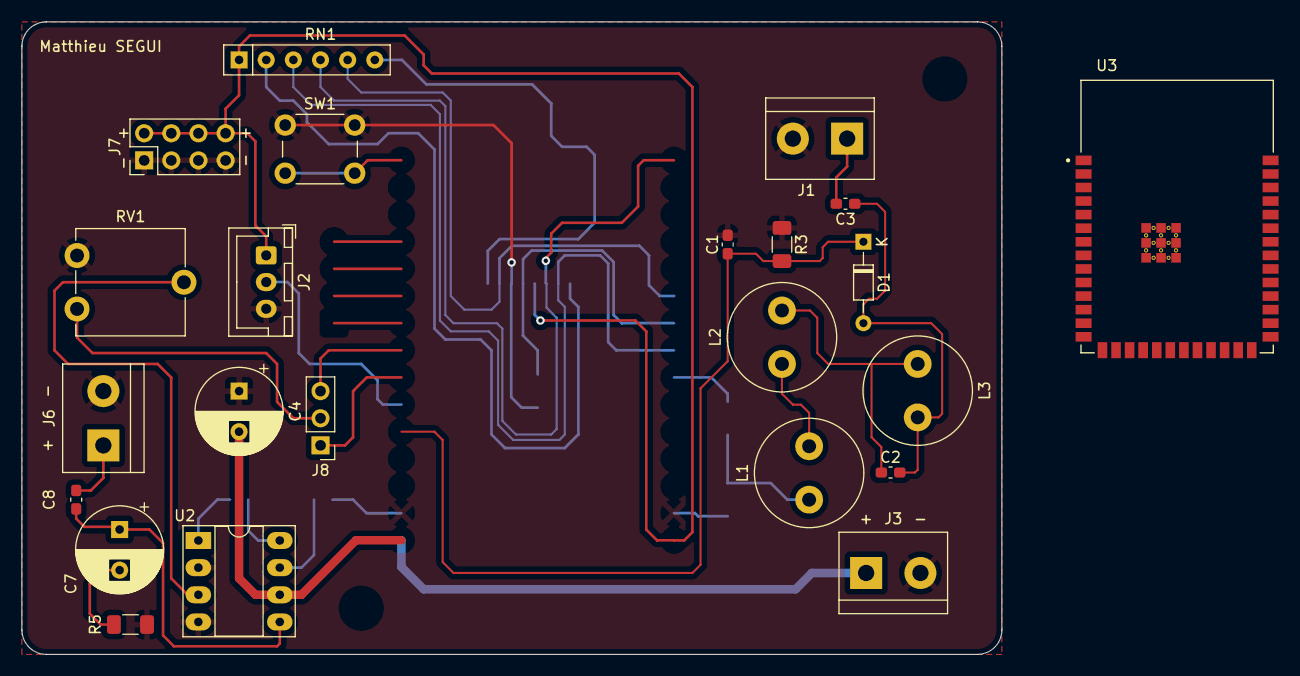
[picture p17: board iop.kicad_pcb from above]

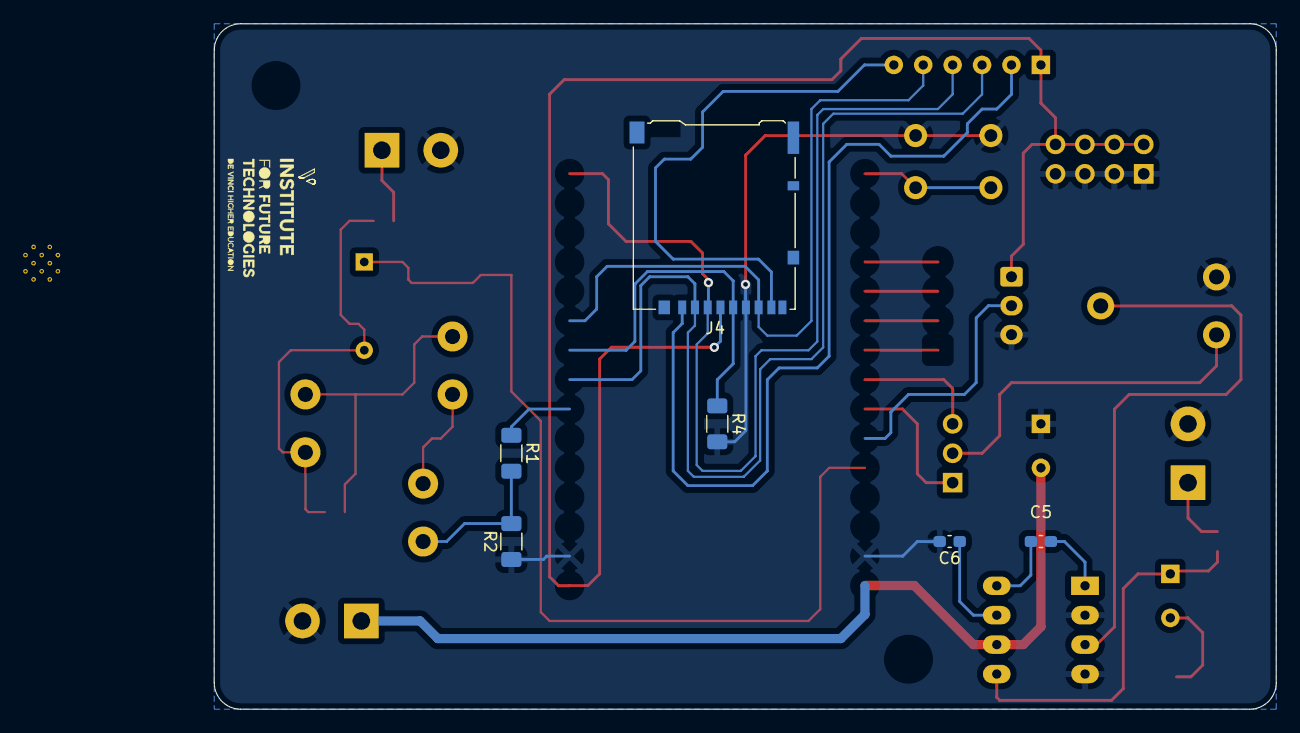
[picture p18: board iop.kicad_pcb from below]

Board: 2 copper layers, 91.7 x 59.2 mm, 29 parts (6 on the bottom side), 24 nets.

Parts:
C1: 100pF; C_0603_1608Metric_Pad1.08x0.95mm_HandSolder
C2: 1nF; C_0603_1608Metric_Pad1.08x0.95mm_HandSolder
C3, C6: 10nF; C_0603_1608Metric_Pad1.08x0.95mm_HandSolder
C4: 100μF; CP_Radial_D8.0mm_P3.80mm
C5, C8: 10μF; C_0603_1608Metric_Pad1.08x0.95mm_HandSolder
C7: 47μF; CP_Radial_D8.0mm_P3.80mm
D1: D; D_DO-34_SOD68_P7.62mm_Horizontal
J1: plant_connector; TerminalBlock_bornier-2_P5.08mm
J2: moisture_sensor_conn; JST_XH_B3B-XH-A_1x03_P2.50mm_Vertical
J3: power_input; TerminalBlock_bornier-2_P5.08mm
J4: micro_sd_slot; microSD_HC_Hirose_DM3AT-SF-PEJM5
J6: speaker_output; TerminalBlock_bornier-2_P5.08mm
J7: ext_pwr_output; PinHeader_2x04_P2.54mm_Vertical
J8: jmp_dacs; PinHeader_1x03_P2.54mm_Vertical
L1, L2, L3: 3.3mH; L_Radial_D10.0mm_P5.00mm_Fastron_07P
R1: 10kΩ; R_1206_3216Metric_Pad1.30x1.75mm_HandSolder
R2: 4.7kΩ; R_1206_3216Metric_Pad1.30x1.75mm_HandSolder
R3: 1MΩ; R_1206_3216Metric_Pad1.30x1.75mm_HandSolder
R4: 100kΩ; R_1206_3216Metric_Pad1.30x1.75mm_HandSolder
R5: 10Ω; R_1206_3216Metric_Pad1.30x1.75mm_HandSolder
RN1: 100kΩ; R_Array_SIP6
RV1: R_Potentiometer; Potentiometer_ACP_CA9-V10_Vertical
SW1: SW_Push; SW_PUSH_6mm
U2: LM386; DIP-8_W7.62mm_Socket_LongPads
U3: ESP32-S3-WROOM-1-N8R8; XCVR_ESP32S3WROOM1N8R8

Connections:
+3V3: J2.1, J4.4, J7.2, J7.4, J7.6, J7.8, RN1.1 (common)
+5V: C4.2, J3.1, U2.6 (V+)
/CLK: J4.5, R4.1
/CS: J4.2, RN1.3 (R2)
/MISO: J4.7, RN1.5 (R4)
/MOSI: J4.3, RN1.4 (R3)
/audio_circuit/sound_input: J8.2, RV1.1
/plant_response: C1.1, D1.1 (K), R3.2
GND: C1.2, C4.1, C6.2, J1.2, J2.3, J3.2, J4.6, J6.2, J7.1, J7.3, J7.5, J7.7, R2.1, R3.1, R4.2, R5.2, RV1.3, SW1.1, U2.2 (-), U2.4 (GND)
unnamed: C2.1, L2.2, L3.1
unnamed: C5.1, U2.1 (GAIN)
unnamed: C5.2, U2.8 (GAIN)
unnamed: C7.1, C8.1, U2.5
unnamed: C7.2, R5.1
unnamed: C2.2, C3.1, D1.2 (A), L3.2
unnamed: C3.2, J1.1
unnamed: J4.1, RN1.2 (R1)
unnamed: J4.8, RN1.6 (R5)
unnamed: C8.2, J6.1
unnamed: L1.1, R1.2, R2.2
unnamed: L1.2, L2.1
unnamed: RV1.2, U2.3 (+)
unnamed: C6.1, U2.7 (BYPASS)
unnamed: U3.1 (GND), U3.40 (GND), U3.41_1 (GND), U3.41_2 (GND), U3.41_3 (GND), U3.41_4 (GND), U3.41_5 (GND), U3.41_6 (GND), U3.41_7 (GND), U3.41_8 (GND), U3.41_9 (GND)

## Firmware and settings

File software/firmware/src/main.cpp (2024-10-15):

#include <Arduino.h>
#include <WiFi.h>
#include <iop_maths_lib.h>

#define BUFFER_SIZE 400
#define LED_PWM_PIN 17
#define MAX_FREQ 300
#define MIN_FREQ 100
#define FREQ_STEP 1
#define ANALOG_PIN 34
#define LED_BUILTIN 2
#define DELAY 50

const char *ssid = "UnknownAPv2";
const char *password = "UbuntuSUDO";

const char *host = "192.168.200.106";
const int port = 3000;

WiFiClient server; // TCP server

const float alpha = 0.99;
const int sweep_data_size = (MAX_FREQ - MIN_FREQ) / FREQ_STEP;
int old_sum = 0;
// float new_standard_dev = 0.0;

float old_standard_dev = 0.0;

int swept_data[sweep_data_size];
float ema[sweep_data_size];
float ema_std[sweep_data_size];
float old_sum_normalized;
float normalized_data[sweep_data_size];

unsigned long time_last_msg = millis();

void setup()
{
  // put your setup code here, to run once:
  Serial.begin(115200);

  // Wifi connection setup

  // Comment
  WiFi.begin(ssid, password);

  while (WiFi.status() != WL_CONNECTED)
  {
    delay(500);
    Serial.println("Connecting to WiFi..");
  }

  Serial.println("Connected to WiFi network");

  // // // Connect to TCP server
  if (!server.connect(host, port))
  {
    Serial.println("Connection to TCP server failed");
    return;
  }

  Serial.println("Connected to TCP server");
  // Uncomment

  Serial.println("Pins setup");
  // GPIO setup
  pinMode(LED_PWM_PIN, OUTPUT);
  pinMode(ANALOG_PIN, INPUT);

  // Initialize data array
  for (int i = 0; i < sweep_data_size; i++)
  {
    swept_data[i] = 0;
    ema[i] = 0;
    ema_std[i] = 1;
  }

  Serial.println("PWM setup");
  // Initialize PWM
  ledcSetup(0, 100000, 2);
  ledcAttachPin(LED_PWM_PIN, 0);
  ledcWrite(0, 2);

  Serial.println("Setup done");

  pinMode(LED_BUILTIN, OUTPUT);
}

void sweep(int *data, int size)
{
  int value = 0;
  for (int index = 0; index < size; index += FREQ_STEP)
  {
    value = analogRead(ANALOG_PIN);
    data[index] = value;
    int freq = MIN_FREQ + index * FREQ_STEP;
    ledcChangeFrequency(0, freq * 1000, 2);
    delayMicroseconds(10);
  }
}

int counter = 0;

void loop()
{
  // put your main code here, to run repeatedly:

  if (!server.connected())
  {
    Serial.println("Connection to TCP server lost");
    delay(1000);
    server.connect(host, port);
    return;
  }
  server.flush();
  sweep(swept_data, sweep_data_size);
  // ema_update(ema, swept_data, sweep_data_size, alpha);
  // ema_std_update(swept_data, sweep_data_size, ema_std, ema, alpha);

  // data_normalizer(swept_data, sweep_data_size, ema, ema_std, normalized_data);

  // float avg = average(normalized_data, sweep_data_size);
  // float standard_dev = standard_deviation(normalized_data, sweep_data_size,avg);

  // int sum_swept_data = int_sum(swept_data, sweep_data_size);
  // float sum_normalized_data = float_sum(normalized_data, sweep_data_size);
  // float diff = abs(sum_normalized_data - old_sum_normalized);
  // int threshed_value =  (diff > 20.0) ? true : false;

  // String message_string = "0 " + String(sum_normalized_data) + " " + String(threshed_value) + " " + String(standard_dev) + " ;\n";

  if (counter < 100 && millis() - time_last_msg > DELAY)
  {
    digitalWrite(LED_BUILTIN, HIGH);
    String message_string = "#";
    String waterfall_string = "";
    for (int i = 0; i < sweep_data_size; i++)
    {
      // server.print(swept_data[i]);
      // server.print(" ");
      // message_string =(swept_data[i] == 0) ? message_string + "0" : message_string + String(swept_data[i]);
      message_string = message_string + String(swept_data[i]);
      message_string = (i < sweep_data_size - 1) ? message_string + " " : message_string;
      // waterfall_string =(swept_data[i] == 0) ? waterfall_string + "0" : waterfall_string + String(swept_data[i]);
      // waterfall_string = ( i > 0 && i < sweep_data_size-1) ? waterfall_string : waterfall_string + ",";
    }
    // Serial.println(message_string);
    message_string = message_string + ";\n";
    Serial.println(message_string);
    server.write(message_string.c_str(), message_string.length());
    time_last_msg = millis();
    counter++;
    digitalWrite(LED_BUILTIN, LOW);
  }
  // Serial.print("Sum : ");
  // Serial.println(sum_swept_data);
  // Serial.print("Sum normalized sweepts : ");
  // Serial.println(sum_normalized_data);
  // Serial.print("Value 0 : ");
  // Serial.println(swept_data[0]);
  // Serial.print("Emas : ");
  // Serial.println(ema[0]);
  // Serial.print("Emas std : ");
  // Serial.println(ema_std[0]);

  // Serial.println();

  // delay(300);
  // old_sum_normalized = sum_normalized_data;
}

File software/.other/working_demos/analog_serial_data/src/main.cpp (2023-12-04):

#include <Arduino.h>

#define LED_PWM_PIN 17
#define MAX_FREQ 300
#define MIN_FREQ 100
#define FREQ_STEP 1
#define ANALOG_PIN 14
#define POWER_3V 13
#define TOGGLE_PIN 33
#define CALIBRATION_STEPS 20


const int nb_values = (int)((MAX_FREQ-MIN_FREQ)/FREQ_STEP);
double freq_array[nb_values];
double calibrating_array[nb_values];

bool isOn = true;

const int esp = 10;

double avg_error = 0;



void plant_sensor_setup(){
    ledcSetup(0, 100000, 2);
    ledcAttachPin(LED_PWM_PIN, 0);  
    ledcWrite(0, 2);
    pinMode(ANALOG_PIN, INPUT);
    delay(5);
}




void plant_sensor_loop(){
    avg_error = 0;
    int values_array[nb_values];
    float value = 0;
    for(unsigned int freq = MIN_FREQ; freq<MAX_FREQ; freq+=FREQ_STEP){
        int index = (freq-MIN_FREQ)/FREQ_STEP;
        value = analogRead(ANALOG_PIN);

        values_array[index] = value;

        ledcChangeFrequency(0, freq*1000, 2);
        // avg += (esp/value);
        delayMicroseconds(10);
    }
    // Serial.println(values_array.toString());
    for(int i = 0; i<nb_values; i++){
      if (i < nb_values-1){
        Serial.print(values_array[i]);
        Serial.print(",");
      }else{
        Serial.println(values_array[i]);
      }
    }
}



void setup() {

  Serial.begin(115200);

  plant_sensor_setup();

}


void socket_communication(){
  
}


void loop() {

  plant_sensor_loop();


}

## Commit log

2023-10-09 Adding README
    [audio_circuit.kicad_sch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]
2024-01-10 New PCB version
    [iop.kicad_pcb, iop.kicad_sch]
2024-01-11 Updating PCB
    [iop.kicad_sch, micro_sd_circuit.kicad_sch]
2024-01-18 Keeping pcb devkit
    [audio_circuit.kicad_sch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]
2024-01-18 Adding budget and BOM
2024-03-06 Adding the possibility to reuse socket
